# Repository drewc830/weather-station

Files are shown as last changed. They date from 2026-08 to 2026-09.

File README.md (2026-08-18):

# Weather Station

This project is a battery-powered environmental monitoring system built around an ESP32 and BME280 sensor. It measures temperature, relative humidity, atmospheric pressure, Wi-Fi signal strength, and battery state, then transmits the measurements over Wi-Fi to a self-hosted server for storage and visualization.

The project was designed as a modular sensor platform rather than a single-purpose weather station. The ESP32 firmware handles sensor acquisition, battery monitoring, network communication, and power management, while a separate server stack receives and stores the measurements and provides historical visualization.
## Prototype

### Closed enclosure

Closed weather station prototype

### Open enclosure

Weather station internal components

## System Architecture

```text
BME280 ──I2C──► ESP32 ──Wi-Fi / HTTP──► FastAPI ──► InfluxDB ──► Grafana
                   ▲
                   │
            Battery Monitoring
```

## Hardware

The current weather station uses:

* ESP32 development board
* BME280 temperature, humidity, and pressure sensor
* 18650 lithium-ion battery
* MT3608 boost converter
* Resistor voltage divider for battery monitoring
* 3D-printed enclosure

The BME280 communicates with the ESP32 over I2C.

## Data Collected

The ESP32 currently sends:

* Temperature
* Relative humidity
* Atmospheric pressure
* Wi-Fi RSSI
* Battery voltage
* Estimated battery percentage

## Firmware

The current firmware is located in:

```text
src/main.cpp
```

The firmware follows a simple measurement cycle:

1. Wake from deep sleep.
2. Initialize the sensor hardware.
3. Connect to Wi-Fi.
4. Collect environmental and battery data.
5. Send the data to the server using HTTP and JSON.
6. Return to deep sleep.

The firmware is built and uploaded using PlatformIO.

To build the firmware:

```bash
pio run
```

To upload it to the ESP32:

```bash
pio run -t upload
```

To open the serial monitor:

```bash
pio device monitor
```

## Power Management

The weather station is powered by a single 18650 lithium-ion cell. The battery voltage is boosted by an MT3608 boost converter, which provides the regulated supply used by the weather station electronics.

Because continuous operation of the ESP32 and Wi-Fi radio would result in unnecessarily high power consumption, the firmware uses the ESP32's deep-sleep mode between measurements.

During each measurement cycle, the ESP32 wakes, initializes the BME280, connects to Wi-Fi, collects sensor and battery measurements, transmits the resulting JSON payload to the server, and returns to deep sleep. The current firmware performs this cycle approximately once per minute.

### Battery Voltage Measurement

Battery voltage is monitored through an ESP32 ADC input. A resistor voltage divider scales the battery voltage before it reaches the ADC.

The firmware reads the ADC multiple times and averages the samples to reduce measurement noise. The measured ADC voltage is then converted back to the estimated battery-terminal voltage using the voltage-divider ratio.

### Battery State-of-Charge Estimation

Lithium-ion battery voltage does not vary linearly with remaining capacity. For this reason, battery percentage is not calculated using a simple linear relationship between maximum and minimum cell voltage.

Instead, the firmware uses a piecewise approximation of the lithium-ion discharge curve to estimate state of charge from the measured battery voltage. This provides a more useful estimate than a linear voltage-to-percentage conversion, although it remains an approximation rather than a direct measurement of remaining capacity.

## Server Side

Sensor data is sent as JSON to a server endpoint.

The server stack is based on:

* FastAPI
* InfluxDB
* Grafana

FastAPI receives HTTP POST requests from the ESP32 and writes the measurements to InfluxDB. Grafana queries the stored time-series data and provides visualization of the measurements over time.

## Configuration

Wi-Fi credentials are stored separately from the main source code and are not included in the repository.

Create:

```text
src/secrets.h
```

with:

```cpp
const char* ssid = "YOUR_WIFI_NAME";
const char* password = "YOUR_WIFI_PASSWORD";
```

The file is excluded from Git using `.gitignore`.

## Repository Structure

```text
weather-station/
├── src/
│   └── main.cpp
├── include/
├── lib/
├── test/
├── hardware/
│   └── enclosure/
├── images/
├── docs/
├── older versions/
├── platformio.ini
├── .gitignore
└── README.md
```

### `src/`

Contains the current ESP32 firmware.

### `hardware/`

Contains physical design files associated with the weather station, including STL files for the 3D-printed enclosure.

### `older versions/`

Contains firmware and test programs created before the project was placed under Git version control. These files are preserved to show earlier stages of development.

Future revisions are tracked through Git commits instead of additional manually numbered versions.

### `docs/`

Reserved for project documentation, wiring information, setup instructions, and related technical notes.

## Current Status

The weather station is operational and has been tested over multi-day periods.

The core firmware, battery monitoring, sensor acquisition, network transmission, data storage, and visualization pipeline are functional.

Further work may include improvements to battery state-of-charge estimation, hardware packaging, documentation, and expansion of the modular sensor platform.

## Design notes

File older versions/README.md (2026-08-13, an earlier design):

# weather-station
A modular ESP32-based sensor platform that collects environmental and system data and sends it to a server for storage, visualization, and long-term analysis.

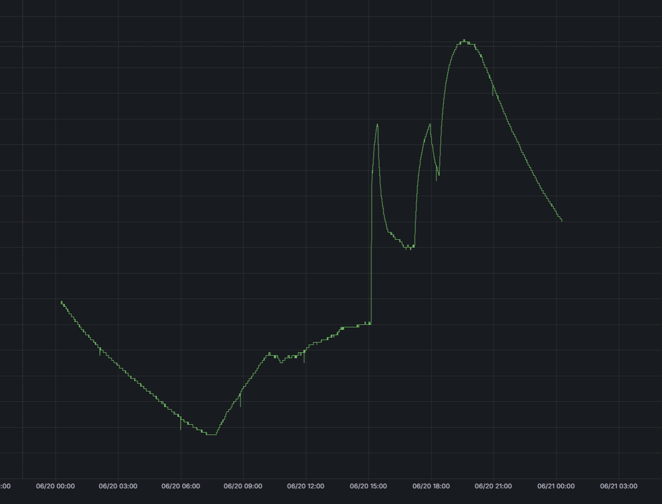
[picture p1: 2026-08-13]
images/dates.png

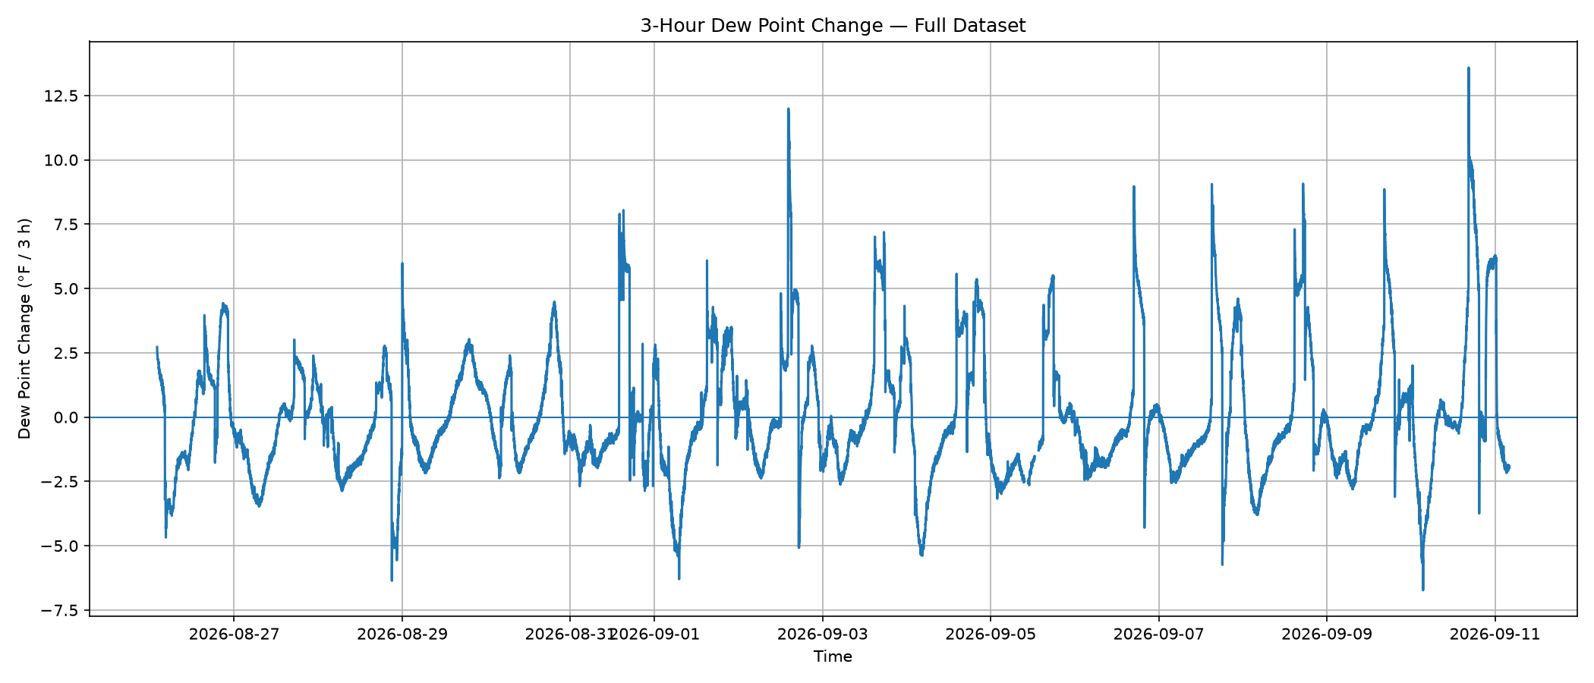
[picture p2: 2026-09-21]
weather-analysis/dewpoint_change_3h.png

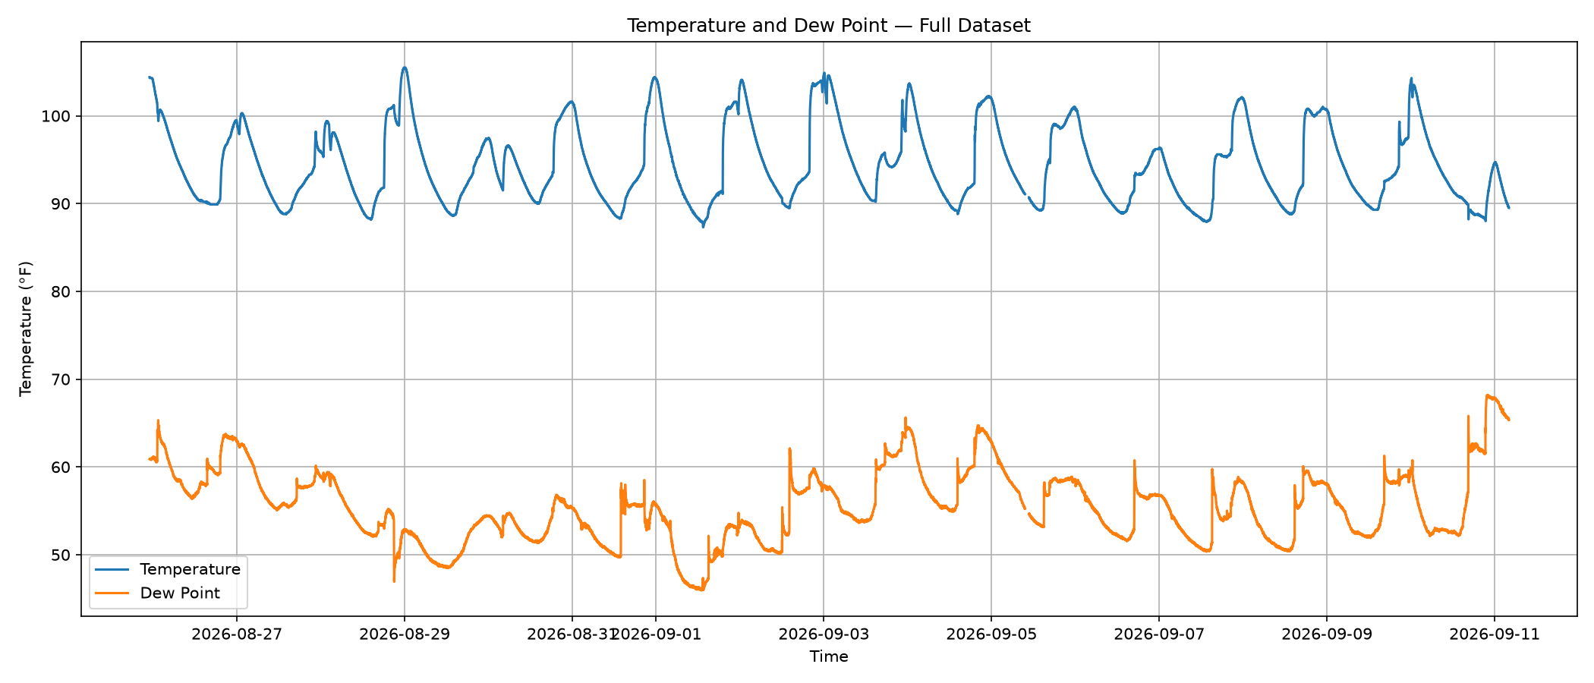
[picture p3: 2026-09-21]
weather-analysis/temperature_dewpoint.png

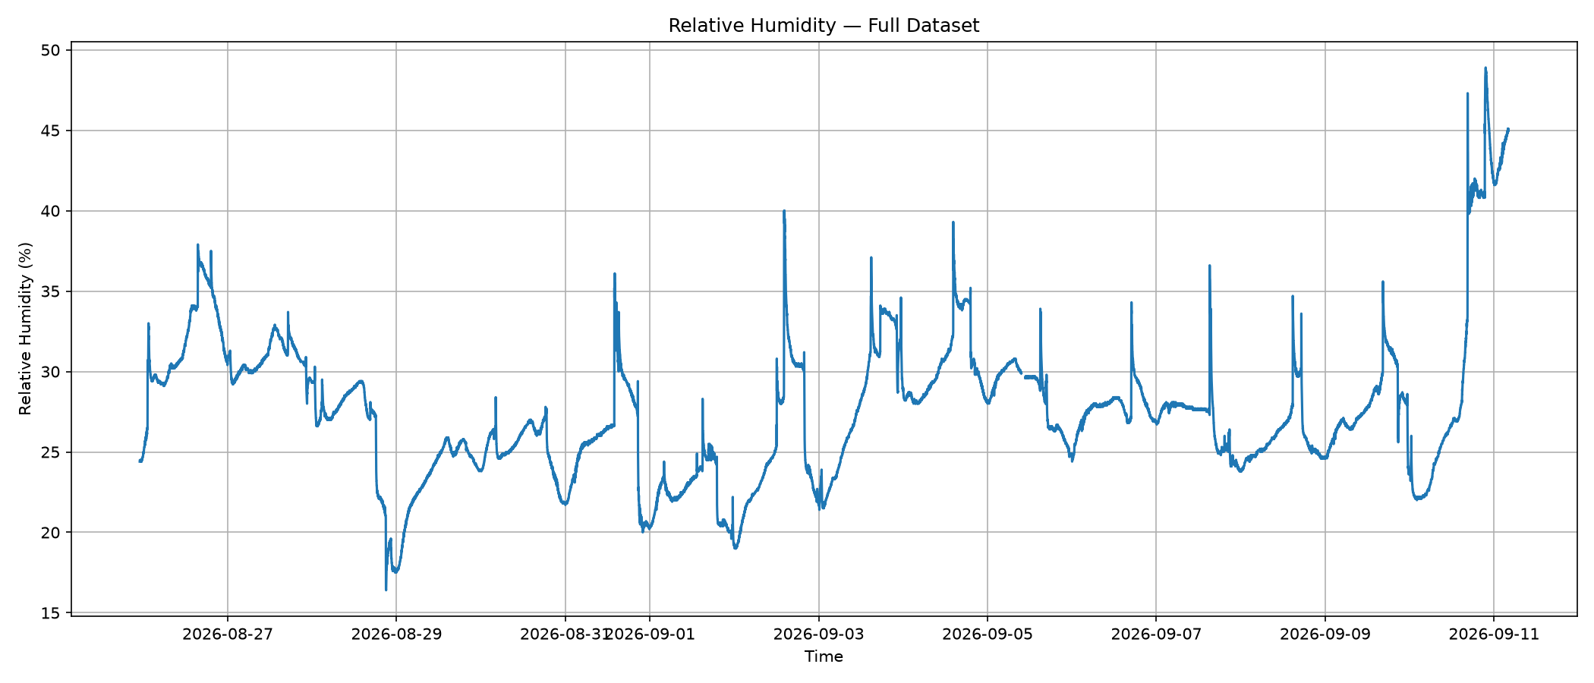
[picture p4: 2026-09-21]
weather-analysis/humidity.png

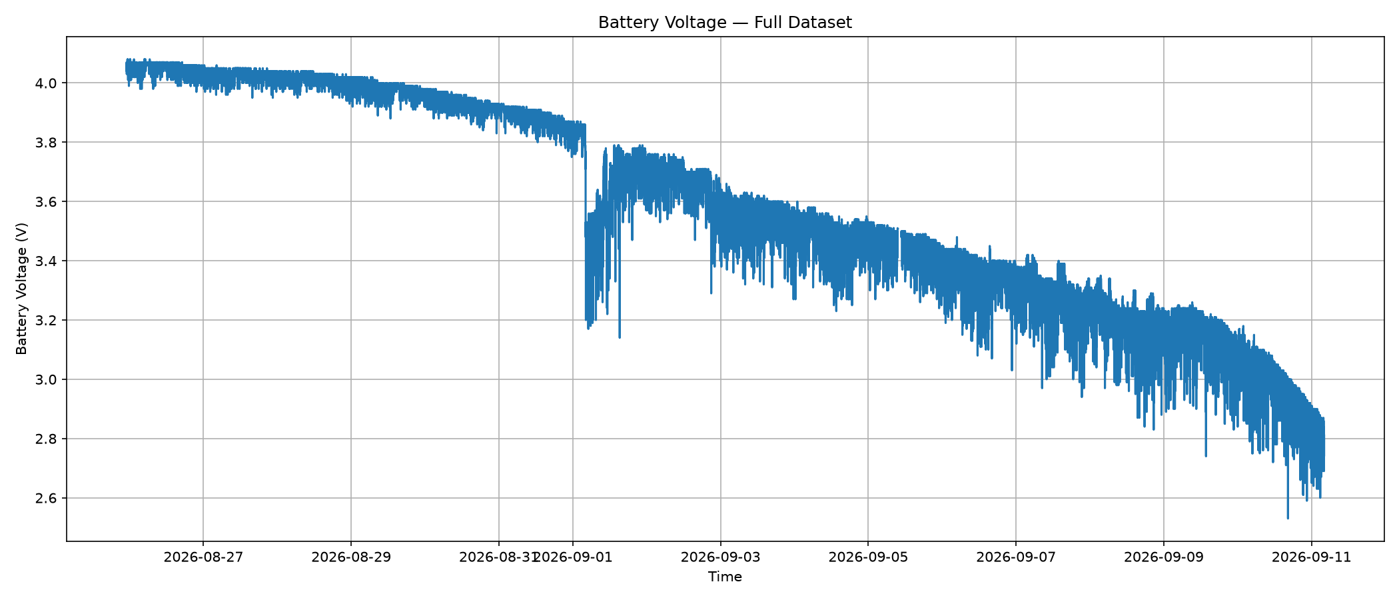
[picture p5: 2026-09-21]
weather-analysis/battery_voltage.png

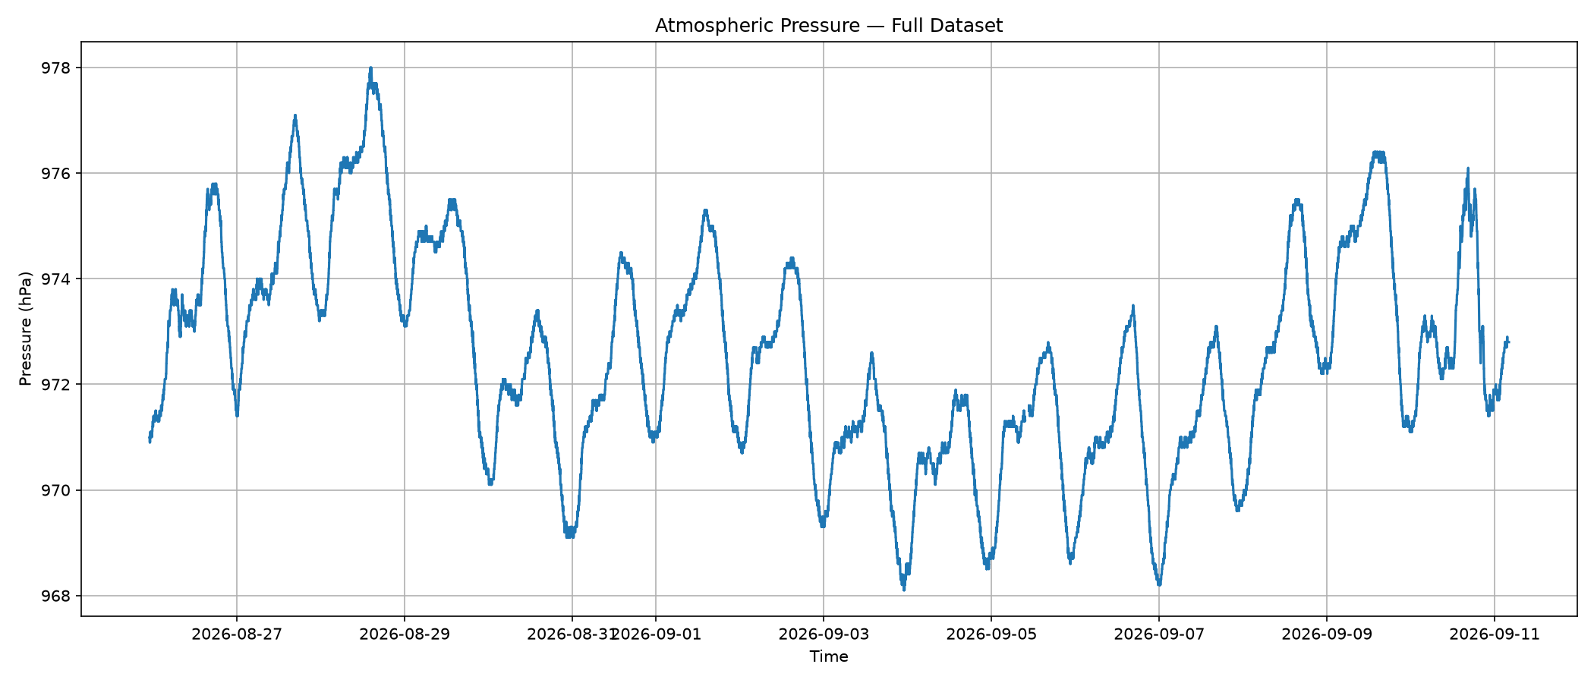
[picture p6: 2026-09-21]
weather-analysis/pressure.png

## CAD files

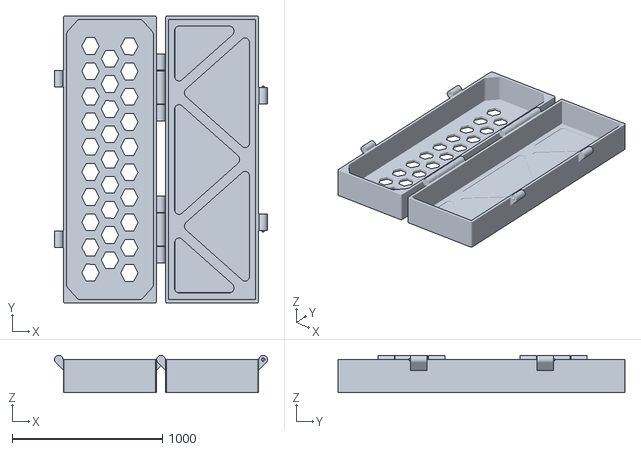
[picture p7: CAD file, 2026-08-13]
hardware/enclosure/breadboard_case_rV1.stl
1418.0 x 1910.0 x 249.0

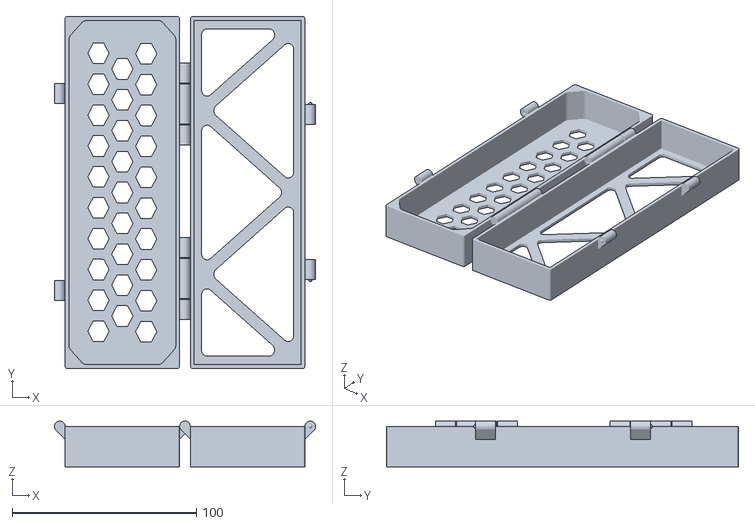
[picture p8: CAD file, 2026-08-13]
hardware/enclosure/Breadboard_Case.stl
141.8 x 191.0 x 24.9

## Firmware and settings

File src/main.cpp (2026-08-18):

#include <Arduino.h>
#include <Wire.h>
#include <Adafruit_BME280.h>
#include <WiFi.h>
#include <HTTPClient.h>
#include <esp_sleep.h>
#include <secrets.h>

#define BME_ADDR 0x77
#define BATTERY_PIN 34
#define SLEEP_TIME_SEC 60
#define SDA_PIN 4
#define SCL_PIN 5

Adafruit_BME280 bme;

//Function to estimate the battery percent from voltage
//can be improved by geting more accurate curves
float batteryPercentFromVoltage(float voltage) {
    if (voltage >= 4.20f) {
        return 100.0f;
    }

    if (voltage >= 4.10f) {
        return 90.0f + ((voltage - 4.10f) / 0.10f) * 10.0f;
    }

    if (voltage >= 4.00f) {
        return 80.0f + ((voltage - 4.00f) / 0.10f) * 10.0f;
    }

    if (voltage >= 3.90f) {
        return 65.0f + ((voltage - 3.90f) / 0.10f) * 15.0f;
    }

    if (voltage >= 3.80f) {
        return 45.0f + ((voltage - 3.80f) / 0.10f) * 20.0f;
    }

    if (voltage >= 3.70f) {
        return 25.0f + ((voltage - 3.70f) / 0.10f) * 20.0f;
    }

    if (voltage >= 3.60f) {
        return 10.0f + ((voltage - 3.60f) / 0.10f) * 15.0f;
    }

    if (voltage >= 3.40f) {
        return 2.0f + ((voltage - 3.40f) / 0.20f) * 8.0f;
    }

    if (voltage >= 3.20f) {
        return ((voltage - 3.20f) / 0.20f) * 2.0f;
    }

    return 0.0f;
}

//function handles connecting to wifi
void connectWiFi() {
    if (WiFi.status() == WL_CONNECTED) {
        return;
    }

    WiFi.mode(WIFI_STA);
    WiFi.begin(ssid, password);

    Serial.print("Connecting to WiFi");

    unsigned long startTime = millis();

    while (
        WiFi.status() != WL_CONNECTED &&
        millis() - startTime < 10000
    ) {
        delay(500);
        Serial.print(".");
    }

    Serial.println();

    if (WiFi.status() == WL_CONNECTED) {
        Serial.println("Connected!");

        Serial.print("IP Address: ");
        Serial.println(WiFi.localIP());
    } else {
        Serial.println("WiFi connection timed out.");
    }
}

//function handles pushing data to API
void postWeather(
    float temperature,
    float humidity,
    float pressure,
    int rssi,
    float batteryVoltage,
    float batteryPercent
) {
    if (WiFi.status() != WL_CONNECTED) {
        Serial.println("WiFi not connected. Skipping POST.");
        return;
    }

    HTTPClient http;

    http.begin(serverUrl);
    http.addHeader("Content-Type", "application/json");
      
    String json = "{";
    json += "\"temperature\":" + String(temperature, 1) + ",";
    json += "\"humidity\":" + String(humidity, 1) + ",";
    json += "\"pressure\":" + String(pressure, 1) + ",";
    json += "\"rssi\":" + String(rssi) + ",";
    json += "\"battery_voltage\":" + String(batteryVoltage, 2) + ",";
    json += "\"battery_percent\":" + String(batteryPercent, 1);
    json += "}";

    Serial.print("POST JSON: ");
    Serial.println(json);

    int responseCode = http.POST(json);

    Serial.print("POST response: ");
    Serial.println(responseCode);

    if (responseCode > 0) {
        Serial.print("Response body: ");
        Serial.println(http.getString());
    } else {
        Serial.print("POST error: ");
        Serial.println(http.errorToString(responseCode));
    }

    http.end();
}

//sleep function to limit power consumption
void enterDeepSleep() {
    Serial.println("Entering deep sleep...");
    Serial.flush();

    WiFi.disconnect(true);
    WiFi.mode(WIFI_OFF);

    esp_sleep_enable_timer_wakeup(
        static_cast<uint64_t>(SLEEP_TIME_SEC) * 1000000ULL
    );

    esp_deep_sleep_start();
}
//function to estimate battery voltage -- needs improvement
float readBatteryVoltage() {
    const int sampleCount = 20;
    uint32_t millivoltTotal = 0;

     //Discard the first reading after startup.
     //The ESP32 ADC can produce an unstable initial sample.
     
    analogReadMilliVolts(BATTERY_PIN);
    delay(10);
 
    //loop stores  samples to be averaged
    for (int i = 0; i < sampleCount; i++) {
        millivoltTotal += analogReadMilliVolts(BATTERY_PIN);
        delay(10);
    }
    //average the samples to improve accuracy
    float averageMillivolts =
        millivoltTotal / static_cast<float>(sampleCount);

     //convert to V
    float dividerVoltage = averageMillivolts / 1000.0f;

    //multiply by factor of 2 to get battery voltage
    //which accounts for equal resistance voltage divider
    float batteryVoltage = dividerVoltage * 2.0f;

    Serial.print("Average ADC millivolts: ");
    Serial.println(averageMillivolts, 1);

    Serial.print("Divider voltage: ");
    Serial.println(dividerVoltage, 3);

    return batteryVoltage;
}

void setup() {
    Serial.begin(115200);
    delay(200);
   
    pinMode(BATTERY_PIN, INPUT);
    analogReadResolution(12); //set ADC input to 12 bit resolution
    analogSetPinAttenuation(BATTERY_PIN, ADC_11db);  //set attenuation to 11dB to so ADC core does not saturate
	
    Wire.begin(SDA_PIN,SCL_PIN); //initalize I2C bus

    //make sure device is connected
    if (!bme.begin(BME_ADDR, &Wire)) { 
        Serial.println("BME280 not found.");
        delay(1000);
        enterDeepSleep();
    }

    Serial.println("BME280 ready.");

    connectWiFi();
}

void loop() {
    float temperatureC = bme.readTemperature();
    float temperatureF =
        (temperatureC * 9.0f / 5.0f) + 32.0f;
    float humidity = bme.readHumidity();
    float pressure = bme.readPressure() / 100.0f;
    float batteryVoltage = readBatteryVoltage();
    float batteryPercent =
        batteryPercentFromVoltage(batteryVoltage);

    batteryPercent = constrain(
        batteryPercent,
        0.0f,
        100.0f
    );
    
    //initalize dummy value indicating no signal
    int rssi = -127;

    if (WiFi.status() == WL_CONNECTED) {
        rssi = WiFi.RSSI();
    }

    Serial.print("WiFi Status: ");
    Serial.println(WiFi.status());

    Serial.print("RSSI: ");
    Serial.print(rssi);
    Serial.println(" dBm");

    Serial.printf(
        "Temp: %.1f F | Humidity: %.1f %% | Pressure: %.1f hPa\n",
        temperatureF,
        humidity,
        pressure
    );

    Serial.printf(
        "Battery: %.2f V | Charge: %.1f %%\n",
        batteryVoltage,
        batteryPercent
    );
    //push data to server
    postWeather(
        temperatureF,
        humidity,
        pressure,
        rssi,
        batteryVoltage,
        batteryPercent
    );

    delay(500);

    enterDeepSleep();
}

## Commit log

2026-08-13 Add weather station firmware and project files
    [Breadboard_Case.stl, breadboard_case_rV1.stl]
2026-08-18 added images of early prototype
2026-09-21 added weather analysis folder with cleaned dataset for a two weeks interval
    [daily-summary.csv, weather-analysis.csv, weather-clean.csv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]
